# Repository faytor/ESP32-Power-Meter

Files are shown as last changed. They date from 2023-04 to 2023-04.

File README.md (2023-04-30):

# Smart AC Power Meter based on ESP32-C3 module
***

> **⚠ WARNING: Project still in progress.**  
> This project is still under development. However, I have successfully tested the following features: 
***
- Flashing and debugging the ESP32 module via USB-C ✅
- Blink the LED on GPIO pin 0 ✅
- I2C communication with the ACS37800 IC (read and write registers) ✅
- Fixed a schematic/hardware bug in the power switch logic (not shown in the image below) ✅
***
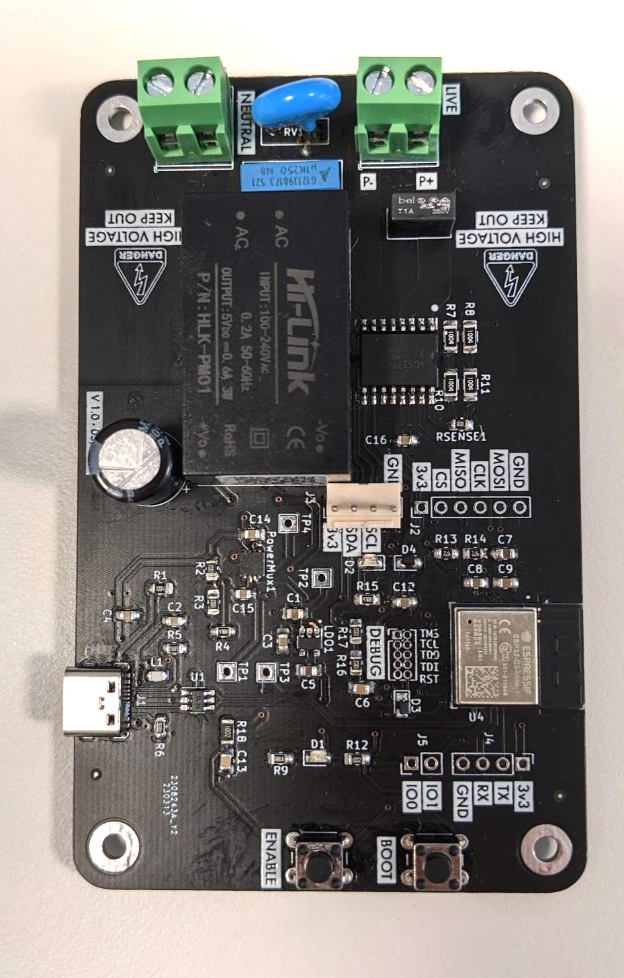
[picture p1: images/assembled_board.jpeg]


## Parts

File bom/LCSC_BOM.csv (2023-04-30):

LCSC Part Number | Manufacture Part Number | Manufacturer | Customer NO. | Package | Description | RoHS | Order Qty. | Min\Mult Order Qty. | Unit Price | Order Price
C165948 | TYPE-C-31-M-12 | Korean Hroparts Elec |  | SMD | 5A 1 16 Female Type-C SMD USB Connectors ROHS | YES | 5 | 5\5 | 0.217400 | 1.09
C209903 | HLK-PM01 | HI-LINK |  | Plugin | 5V 0.6A 90VAC~265VAC 120V~350V 3W AC-DC 73% Plugin Power Modules ROHS | YES | 2 | 1\1 | 2.512.100 | 5.02
C709041 | JL500-50802G01 | JILN |  | P=5.08mm | Copper -40℃~+105℃ 15A 300V Green Tin 14~26 250℃ 5.08mm 0.2~2 1 2 P=5.08mm Screw terminal ROHS | YES | 10 | 5\5 | 0.132500 | 1.33
C363068 | STE10D561K1EQ0FST0R0 | STE(Songtian Elec) |  | Plugin | 925V 460V 350V 504V~616V Plugin Varistors ROHS | YES | 5 | 5\5 | 0.081400 | 0.41
C437645 | 50ZLH220MEFCT810X16 | Rubycon |  | Plugin,D10xL16mm | 220uF 50V 10mm 16mm 5mm ±20% 10000hrs@105℃ Plugin,D10xL16mm Aluminum Electrolytic Capacitors - Leaded ROHS | YES | 5 | 5\5 | 0.178200 | 0.89
C117677 | B32521C3104K189 | TDK |  | Plugin,P=10mm | ±10% 250V 100nF -55℃~+125℃ Metallized Polyester Plugin,P=10mm Film Capacitors ROHS | YES | 5 | 1\1 | 0.271900 | 1.36
C434330 | MEF104K250D02 | Jimson |  | Plugin,P=10mm | ±10% 250V 100nF -40℃~+85℃ PET Plugin,P=10mm Film Capacitors ROHS | YES | 5 | 5\5 | 0.079400 | 0.40
C479110 | PTFR1206B1M00P9 | Resistor.Today |  | 1206 | 250mW Thin Film Resistor 200V ±25ppm/℃ ±0.1% -55℃~+125℃ 1MΩ 1206 Chip Resistor - Surface Mount ROHS | YES | 20 | 5\5 | 0.208900 | 4.18
C2849373 | PTFR0805B8K20P9 | Resistor.Today |  | 805 | 0.13W Thin Film Resistor 150V ±0.1% -55℃~+155℃ 8.2kΩ 0805 Chip Resistor - Surface Mount ROHS | YES | 10 | 5\5 | 0.140300 | 1.40
C140321 | TPS2115ADRBR | Texas Instruments |  | SON-8(3x3) | SON-8(3x3) Battery Management ICs ROHS | YES | 3 | 1\1 | 1.778.700 | 5.34
C9055 | SPX3819M5-L-3-3/TR | MaxLinear |  | SOT-23-5 | 500mA 70dB Fixed 3.3V~3.3V Positive 16V SOT-23-5 Linear Voltage Regulators (LDO) ROHS | YES | 5 | 1\5 | 0.167900 | 0.84
C7519 | USBLC6-2SC6 | STMicroelectronics |  | SOT-23-6 | 6V 17V Unidirectional 5.25V SOT-23-6 ESD Protection Devices ROHS | YES | 5 | 5\5 | 0.120500 | 0.60
C964055 | HBLS2012-2N2S | HYHONGYEX |  | 805 | 600mA 2.2nH 100mΩ 0805 Inductors (SMD) ROHS | YES | 50 | 1\50 | 0.010400 | 0.52
C2895038 | B-2101S10P-B110 | Ckmtw(Shenzhen Cankemeng) |  | Plugin,P=1.27mm | 1A Straight Square Pins 1mm 3mm -40℃~+105℃ 1.8mm 10 1.27mm 双排 Black 1.27mm 2x5P Plugin,P=1.27mm Pin Headers ROHS | YES | 5 | 5\5 | 0.079200 | 0.40
C193404 | 1N4007WS | MDD（Microdiode Electronics） |  | SOD-323 | 1A 1kV 1.1V@1A SOD-323 Diodes - General Purpose ROHS | YES | 20 | 20\20 | 0.031400 | 0.63
C2838502 | ESP32-C3-MINI-1-N4 | Espressif Systems |  | SMD,13.2x16.6mm | SMD,13.2x16.6mm RF Modules ROHS | YES | 2 | 1\1 | 2.545.500 | 5.09
C5355440 | A-SC170Y3C-A01-3T | Amicc |  | 805 | 20mA Colorless transparence 140mcd 588.5nm~594.5nm -40℃~+85℃ 正贴 yellow 140° 60mW 1.7V~2.3V 0805 Light Emitting Diodes (LED) ROHS | YES | 10 | 10\10 | 0.054700 | 0.55
C520082 | CC0805JRX7R7BB104 | YAGEO |  | 805 | 16V 100nF X7R ±5% 0805 Multilayer Ceramic Capacitors MLCC - SMD/SMT ROHS | YES | 50 | 50\50 | 0.012400 | 0.62
C2180714 | CC0805MRX7R8BB103 | YAGEO |  | 805 | 25V 10nF X7R ±20% 0805 Multilayer Ceramic Capacitors MLCC - SMD/SMT ROHS | YES | 50 | 50\50 | 0.006500 | 0.33
C87157 | EMK212BJ106KG-T | Taiyo Yuden |  | 805 | 16V 10uF X5R ±10% 0805 Multilayer Ceramic Capacitors MLCC - SMD/SMT ROHS | YES | 50 | 50\50 | 0.015900 | 0.80
C204548 | CR0805-FX-5101ELF | BOURNS |  | 805 | 125mW ±100ppm/℃ ±1% 5.1kΩ 0805 Chip Resistor - Surface Mount ROHS | YES | 50 | 50\50 | 0.012400 | 0.62
C204522 | CR0805-FX-4700ELF | BOURNS |  | 805 | 125mW Thick Film Resistors ±100ppm/℃ ±1% -55℃~+155℃ 470Ω 0805 Chip Resistor - Surface Mount ROHS | YES | 50 | 50\50 | 0.012800 | 0.64
C237770 | RMCF0805JT4K70 | SEI(Stackpole Elec) |  | 805 | 125mW 150V ±200ppm/℃ ±5% -55℃~+125℃ 4.7kΩ 0805 Chip Resistor - Surface Mount ROHS | YES | 50 | 50\50 | 0.006800 | 0.34

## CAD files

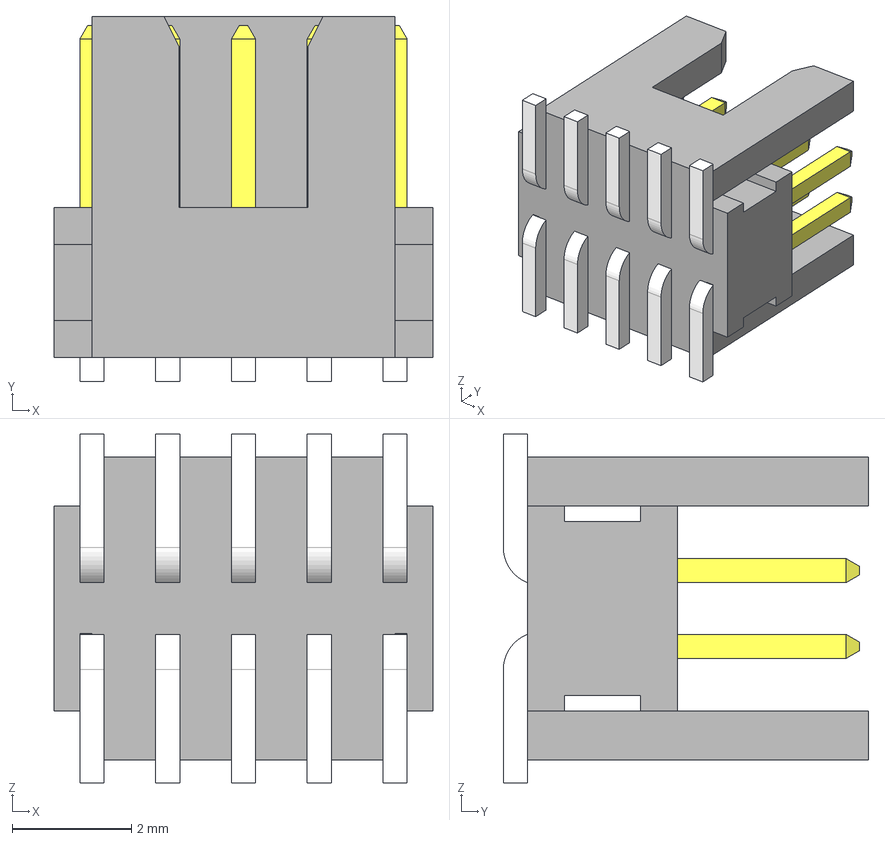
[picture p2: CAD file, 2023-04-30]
KicadLibrary/FTSH-105-01-F-DV-P-TR/FTSH-105-01-F-DV-P-TR.step
6.35 x 6.12 x 5.84 mm
FTSH-105-01-F-DV-K_pins2
FTSH-105-01-F-DV-K_pins1
FTSH-105-01-F-DV-K_body

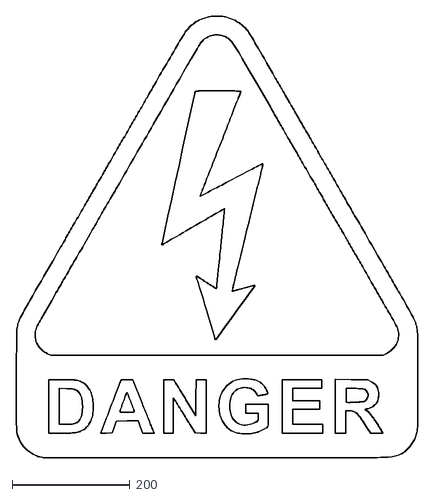
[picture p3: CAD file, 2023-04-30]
KicadLibrary/HighVoltageDanger.dxf
681.1 x 749.9

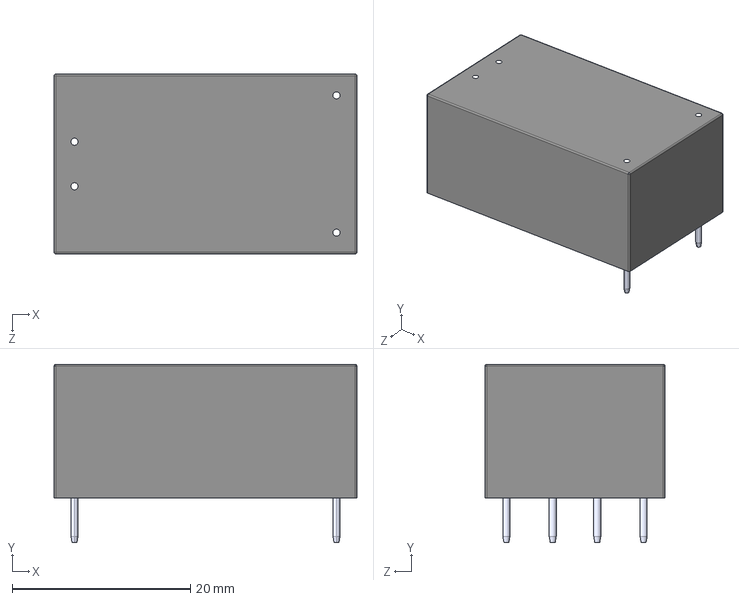
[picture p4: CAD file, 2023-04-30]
KicadLibrary/hlk_pm01/hlk-pm01--3DModel-STEP-56544.STEP
34.0 x 20.0 x 20.2 mm

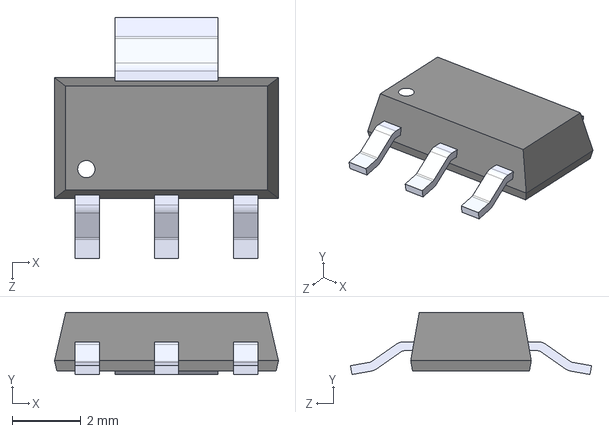
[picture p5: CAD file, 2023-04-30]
KicadLibrary/LD1117S33CTR/LD1117S33CTR.step
6.50 x 1.80 x 7.00 mm

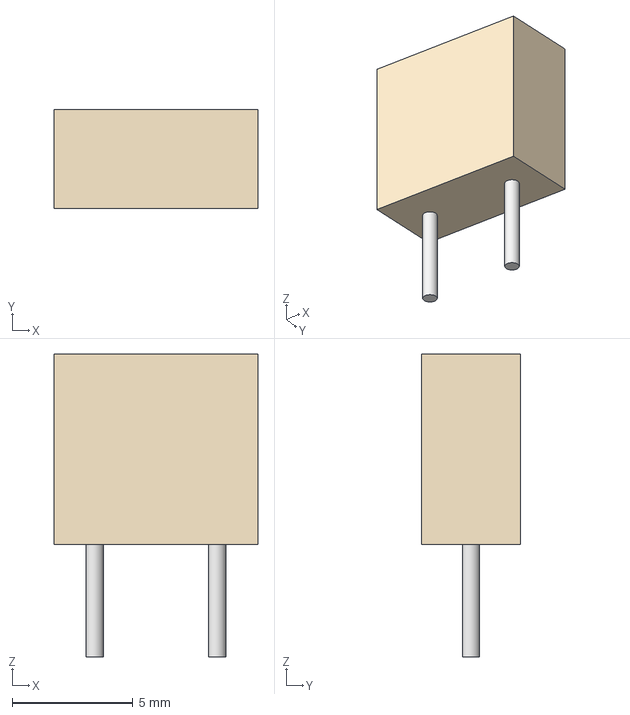
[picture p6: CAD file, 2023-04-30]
KicadLibrary/RST-1-BULK/RST_BEL.step
8.46 x 4.09 x 12.6 mm

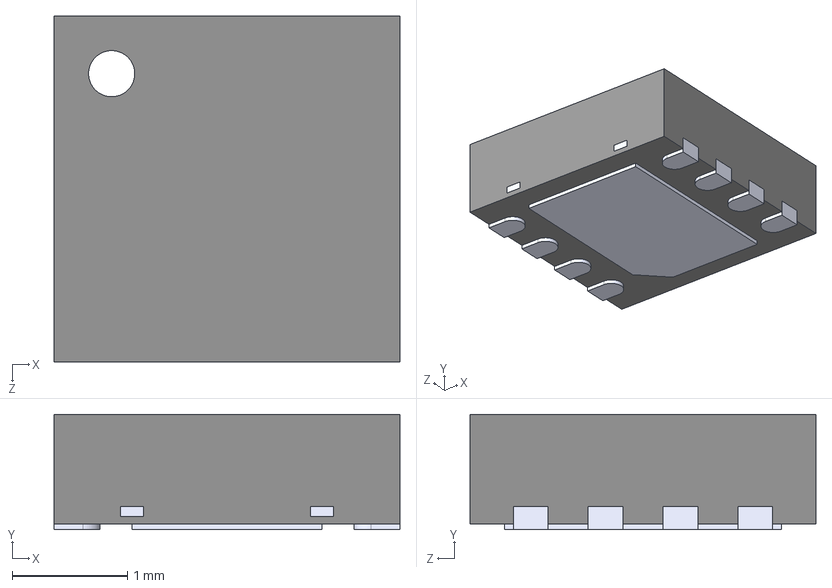
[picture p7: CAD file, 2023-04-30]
KicadLibrary/TPS2115ADRBR/TPS2115ADRBR--3DModel-STEP-56544.STEP
3.00 x 1.00 x 3.00 mm

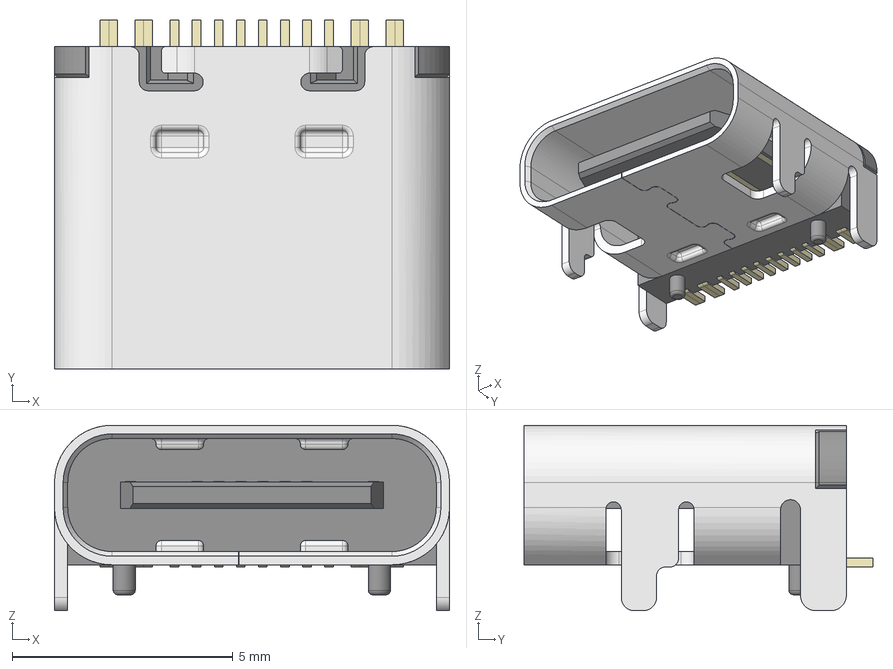
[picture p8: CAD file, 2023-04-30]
KicadLibrary/usb_3d/type-c-31-m-12-1.snapshot.5/HRO_TYPE-C-31-M-12.step
8.95 x 7.90 x 4.20 mm

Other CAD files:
KicadLibrary/ACS37800KMACTR-090B3-I2C/Allegro/soic127p1030x265-16n.psm

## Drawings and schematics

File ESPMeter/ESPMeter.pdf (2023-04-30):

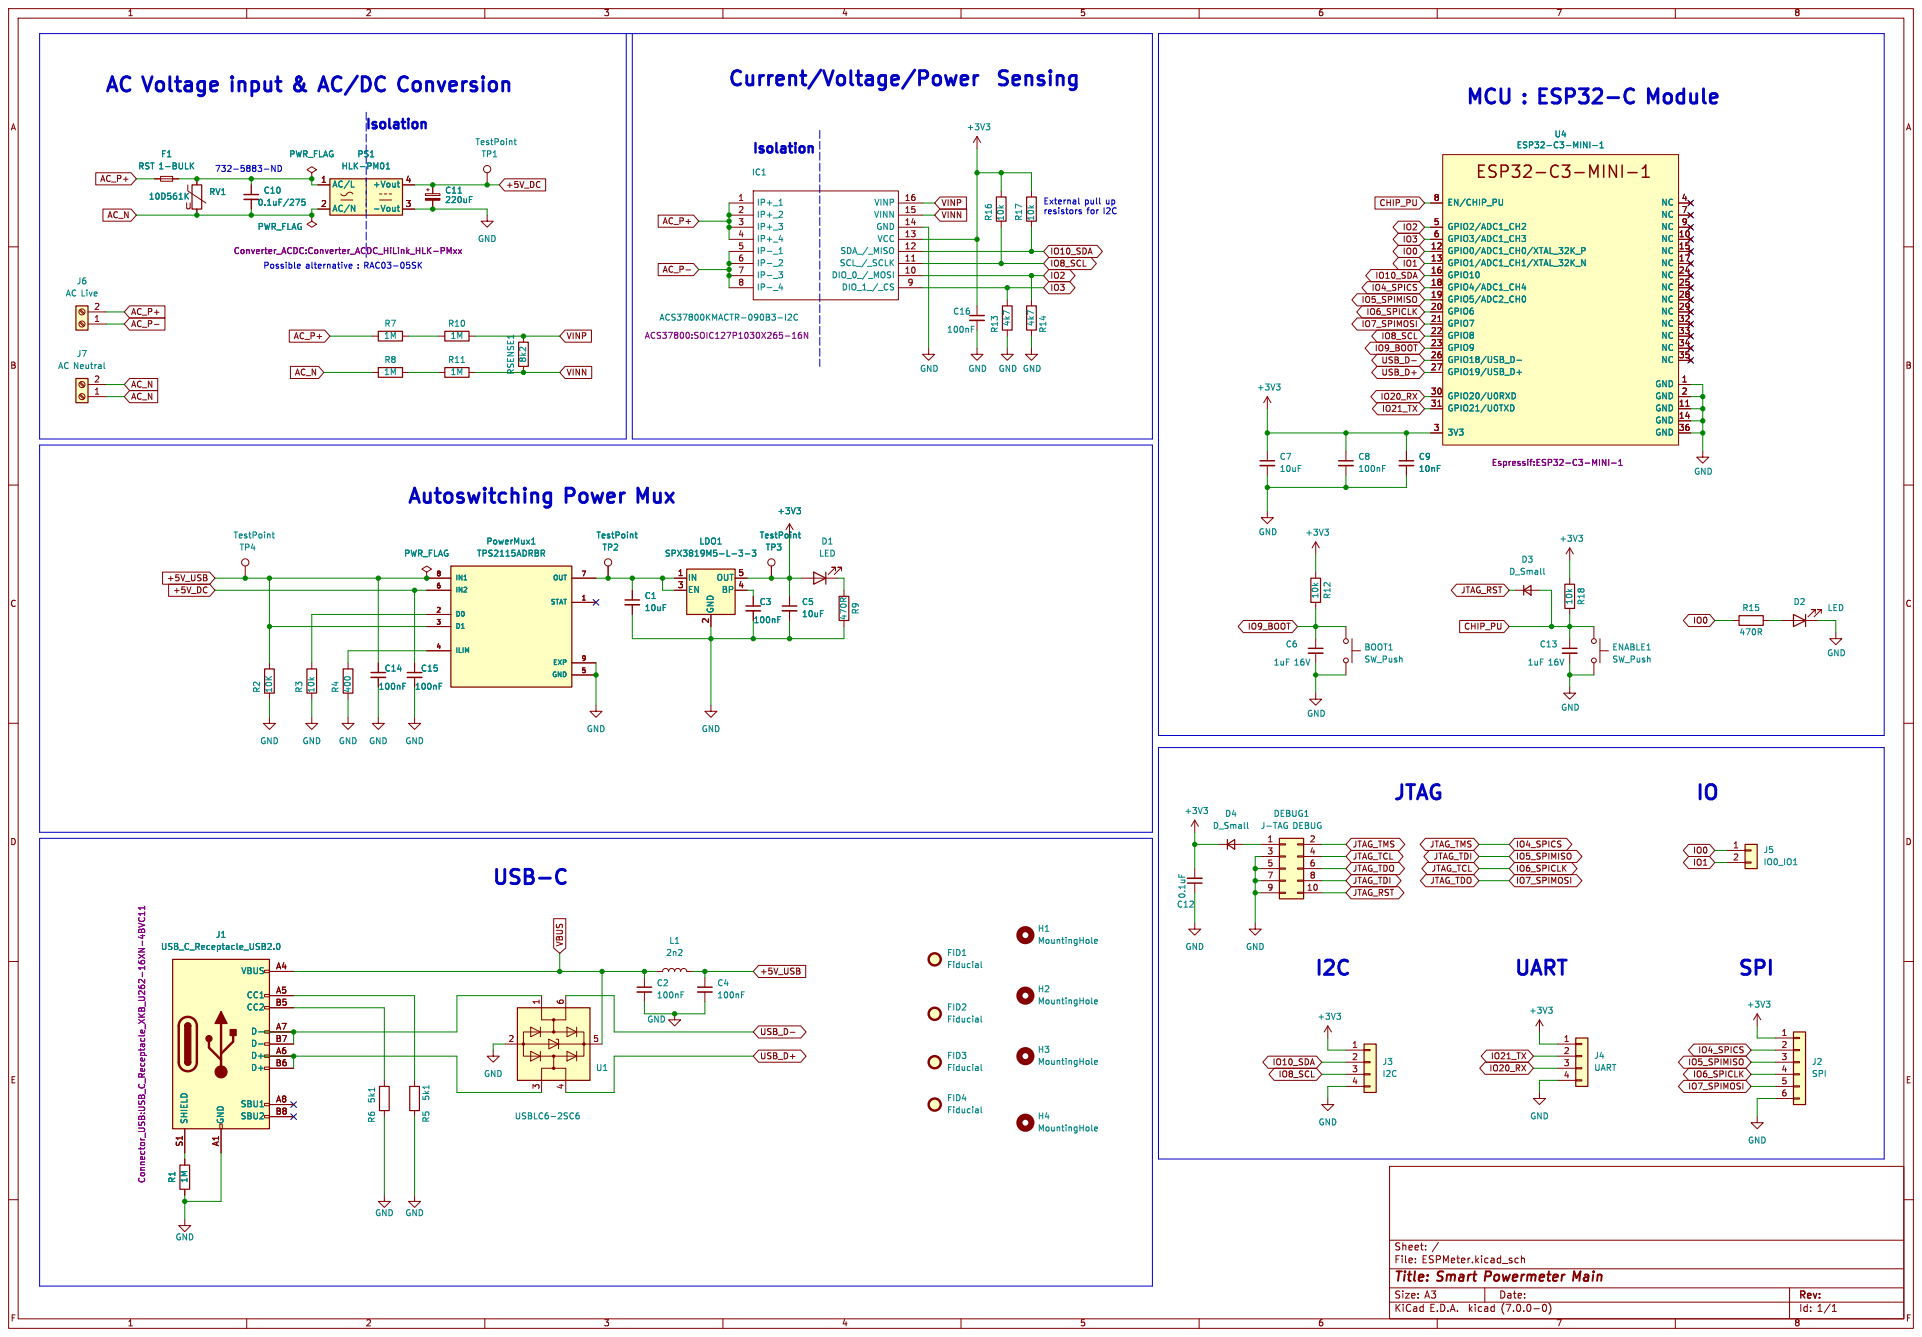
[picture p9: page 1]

resistors for I2C AC Voltage input & AC/DC Conversion

2 EN 3 BP 4 OUT 5 +3V3 TP2 TestPoint C5

Id: 1/1 Title: Smart Powermeter Main

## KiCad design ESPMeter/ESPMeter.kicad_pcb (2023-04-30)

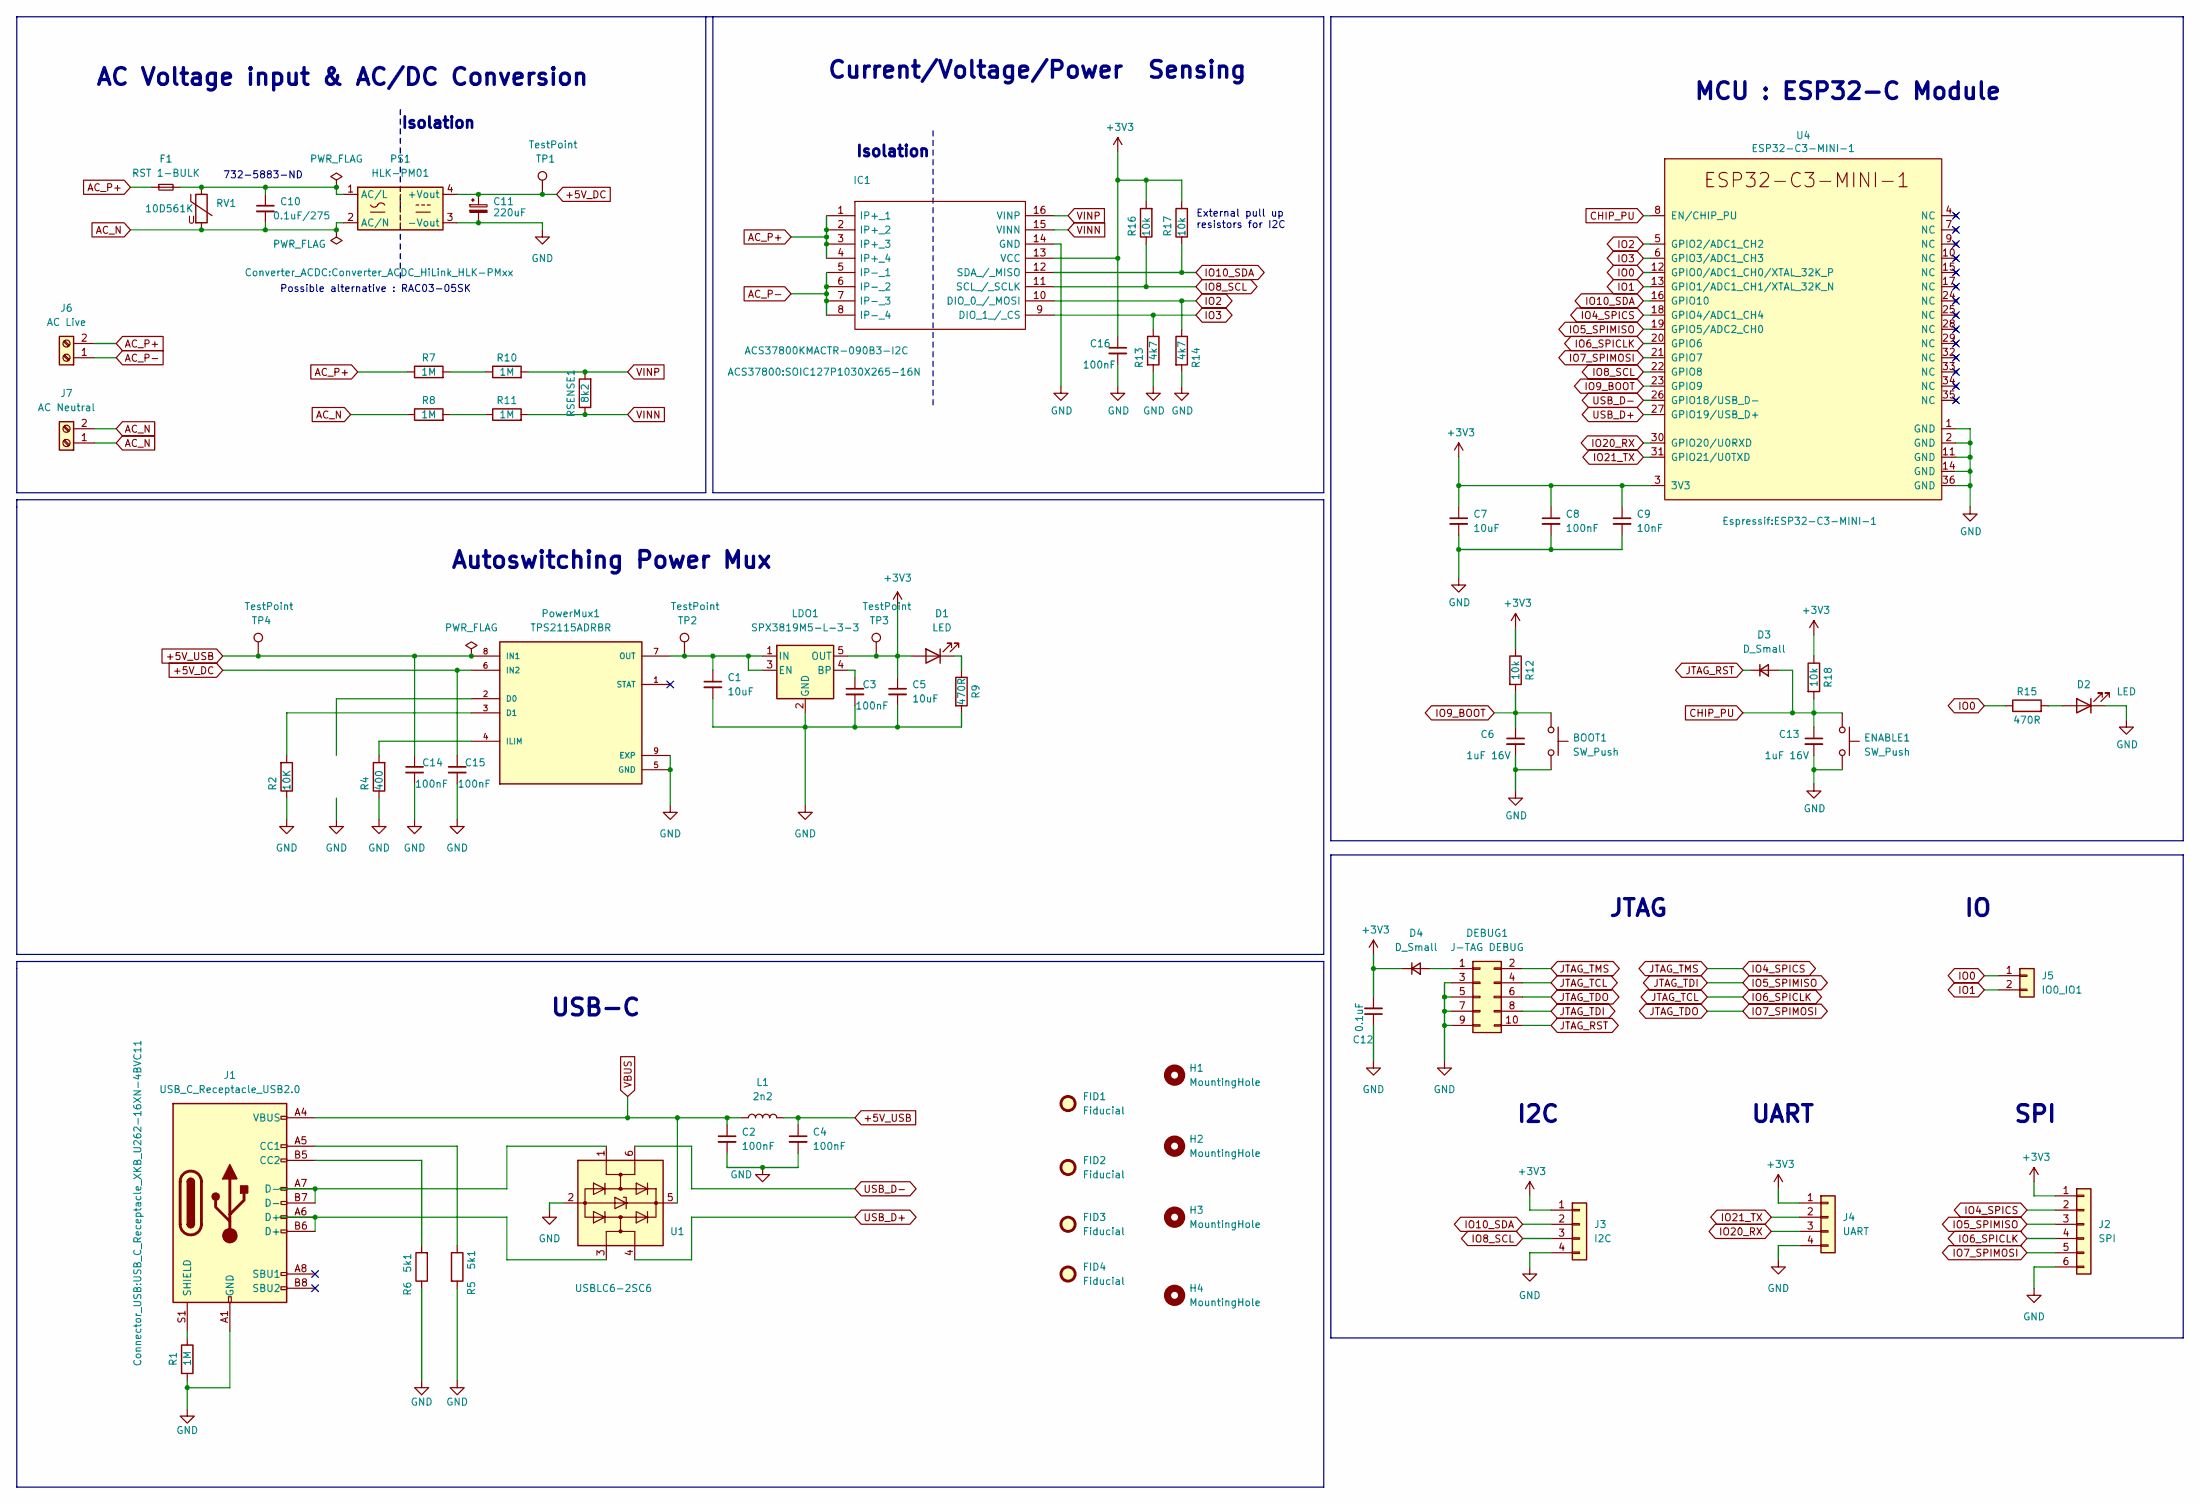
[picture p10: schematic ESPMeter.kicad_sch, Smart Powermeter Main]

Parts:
BOOT1: SW_Push; SW_PUSH_6mm_H4.3mm
C1, C5, C7: 10uF; C_0805_2012Metric_Pad1.18x1.45mm_HandSolder
C2, C3, C4, C8, C14, C15, C16: 100nF; C_0805_2012Metric_Pad1.18x1.45mm_HandSolder
C6, C13: 1uF 16V; C_0805_2012Metric_Pad1.18x1.45mm_HandSolder; LCSC C52923
C9: 10nF; C_0805_2012Metric_Pad1.18x1.45mm_HandSolder
C10: 0.1uF/275; C_Rect_L13.0mm_W8.0mm_P10.00mm_FKS3_FKP3_MKS4
C11: 220uF; CP_Radial_D10.0mm_P5.00mm
C12: 0.1uF; C_0805_2012Metric_Pad1.18x1.45mm_HandSolder
D1: LED; LED_0805_2012Metric_Pad1.15x1.40mm_HandSolder
D2: LED; LED_0805_2012Metric_Pad1.15x1.40mm_HandSolder; LCSC C2286
D3, D4: D_Small; D_0805_2012Metric_Pad1.15x1.40mm_HandSolder
DEBUG1: J-TAG DEBUG; PinHeader_2x05_P1.27mm_Vertical
ENABLE1: SW_Push; SW_PUSH_6mm_H4.3mm
F1: RST 1-BULK; FUSE_RST-1-BULK
FID1, FID2, FID3, FID4: Fiducial; Fiducial_0.5mm_Mask1.5mm
H1, H2, H3, H4: MountingHole; MountingHole_3.2mm_M3_Pad_TopBottom
IC1: ACS37800KMACTR-090B3-I2C; SOIC127P1030X265-16N; Manufacturer_Part_Number ACS37800KMACTR-090B3-I2C
J1: USB_C_Receptacle_USB2.0; USB_C_Receptacle_XKB_U262-16XN-4BVC11
J2: SPI; PinHeader_1x06_P2.54mm_Vertical
J3: I2C; PinHeader_1x04_P2.54mm_Vertical
J4: UART; PinHeader_1x04_P2.54mm_Vertical
J5: IO0_IO1; PinHeader_1x02_P2.54mm_Vertical
J6: AC Live; TerminalBlock_Phoenix_MKDS-3-2-5.08_1x02_P5.08mm_Horizontal
J7: AC Neutral; TerminalBlock_Phoenix_MKDS-3-2-5.08_1x02_P5.08mm_Horizontal
L1: 2n2; L_0805_2012Metric_Pad1.15x1.40mm_HandSolder
LDO1: SPX3819M5-L-3-3; SOT-23-5
PS1: HLK-PM01; Converter_ACDC_HiLink_HLK-PMxx
PowerMux1: TPS2115ADRBR; SON65P300X300X100-9N
R1: 1M; R_0805_2012Metric_Pad1.20x1.40mm_HandSolder
R2: 10K; R_0805_2012Metric_Pad1.20x1.40mm_HandSolder
R4: 400; R_0805_2012Metric_Pad1.20x1.40mm_HandSolder
R5, R6: 5k1; R_0805_2012Metric_Pad1.20x1.40mm_HandSolder
R7, R8, R10, R11: 1M; R_1206_3216Metric_Pad1.30x1.75mm_HandSolder
R9, R15: 470R; R_0805_2012Metric_Pad1.20x1.40mm_HandSolder
R12, R16, R17, R18: 10k; R_0805_2012Metric_Pad1.20x1.40mm_HandSolder
R13, R14: 4k7; R_0805_2012Metric_Pad1.20x1.40mm_HandSolder
RSENSE1: 8k2; R_0805_2012Metric_Pad1.20x1.40mm_HandSolder
RV1: 10D561K; RV_Disc_D9mm_W3.5mm_P5mm
TP1, TP2, TP3, TP4: TestPoint; TestPoint_THTPad_2.0x2.0mm_Drill1.0mm
U1: USBLC6-2SC6; SOT-23-6_Handsoldering
U4: ESP32-C3-MINI-1; LCSC C2838502

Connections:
+3V3: C5.1, C7.1, C8.1, C9.1, C12.2, C16.1, D1.2 (A), D4.1 (K), IC1.13 (VCC), J2.1, J3.1, J4.1, LDO1.5 (OUT), R12.1, R16.2, R17.2, R18.1, TP3.1, U4.3 (3V3)
+5V_DC: C11.1, C15.1, PS1.4 (+Vout), PowerMux1.6 (IN2), TP1.1
AC_N: C10.2, J7.1, J7.2, PS1.2 (AC/N), R8.1, RV1.2
AC_P+: F1.1, IC1.1 (IP+_1), IC1.2 (IP+_2), IC1.3 (IP+_3), IC1.4 (IP+_4), J6.2, R7.1
AC_P-: IC1.5 (IP-_1), IC1.6 (IP-_2), IC1.7 (IP-_3), IC1.8 (IP-_4), J6.1
CHIP_PU: C13.1, D3.2 (A), ENABLE1.1, R18.2, U4.8 (EN/CHIP_PU)
GND: BOOT1.2, C1.2, C2.2, C3.2, C4.2, C5.2, C6.2, C7.2, C8.2, C9.2, C11.2, C12.1, C13.2, C14.2, C15.2, C16.2, D2.1 (K), DEBUG1.3, DEBUG1.5, DEBUG1.7, DEBUG1.9, ENABLE1.2, IC1.14 (GND), J1.A1 (GND), J1.A12 (GND), J1.B1 (GND), J1.B12 (GND), J2.6, J3.4, J4.4, LDO1.2 (GND), PS1.3 (-Vout), PowerMux1.5 (GND), PowerMux1.9 (EXP), R1.2, R2.1, R4.1, R5.2, R6.1, R9.2, R13.2, R14.2, U1.2 (GND), U4.1 (GND), U4.2 (GND), U4.11 (GND), U4.14 (GND), U4.36 (GND); also elsewhere on the board
IO0: J5.1, R15.1, U4.12 (GPIO0/ADC1_CH0/XTAL_32K_P)
IO1: J5.2, U4.13 (GPIO1/ADC1_CH1/XTAL_32K_N)
IO2: IC1.10 (DIO_0_/_MOSI), R14.1, U4.5 (GPIO2/ADC1_CH2)
IO3: IC1.9 (DIO_1_/_CS), R13.1, U4.6 (GPIO3/ADC1_CH3)
IO4_SPICS: DEBUG1.2, J2.2, U4.18 (GPIO4/ADC1_CH4)
IO5_SPIMISO: DEBUG1.8, J2.3, U4.19 (GPIO5/ADC2_CH0)
IO6_SPICLK: DEBUG1.4, J2.4, U4.20 (GPIO6)
IO7_SPIMOSI: DEBUG1.6, J2.5, U4.21 (GPIO7)
IO8_SCL: IC1.11 (SCL_/_SCLK), J3.3, R16.1, U4.22 (GPIO8)
IO9_BOOT: BOOT1.1, C6.1, R12.2, U4.23 (GPIO9)
IO10_SDA: IC1.12 (SDA_/_MISO), J3.2, R17.1, U4.16 (GPIO10)
IO20_RX: J4.3, U4.30 (GPIO20/U0RXD)
IO21_TX: J4.2, U4.31 (GPIO21/U0TXD)
JTAG_RST: D3.1 (K), DEBUG1.10
unnamed: C10.1, F1.2, PS1.1 (AC/L), RV1.1
unnamed: D1.1 (K), R9.1
unnamed: D2.2 (A), R15.2
unnamed: D4.2 (A), DEBUG1.1
unnamed: J1.A5 (CC1), R5.1
unnamed: J1.B5 (CC2), R6.2
unnamed: J1.A6 (D+), J1.B6 (D+), U1.3 (I/O2)
unnamed: J1.A7 (D-), J1.B7 (D-), U1.1 (I/O1)
unnamed: J1.S1 (SHIELD), R1.1
unnamed: C3.1, LDO1.4 (BP)
unnamed: C1.1, LDO1.1 (IN), LDO1.3 (EN), PowerMux1.7 (OUT), TP2.1
unnamed 32: PowerMux1.2 (D0); also elsewhere on the board
unnamed: PowerMux1.4 (ILIM), R4.2
unnamed: R7.2, R10.1
unnamed: R8.2, R11.1
USB_D+: U1.4 (I/O2), U4.27 (GPIO19/USB_D+)
USB_D-: U1.6 (I/O1), U4.26 (GPIO18/USB_D-)
VBUS: C2.1, J1.A4 (VBUS), J1.A9 (VBUS), J1.B4 (VBUS), J1.B9 (VBUS), L1.1, U1.5 (VBUS)
VINN: IC1.15 (VINN), R11.2, RSENSE1.1
VINP: IC1.16 (VINP), R10.2, RSENSE1.2

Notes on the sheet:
UART
External pull up resistors for I2C
SPI
AC Voltage input & AC/DC Conversion
JTAG
Current/Voltage/Power Sensing
I2C
Autoswitching Power Mux
Isolation
Possible alternative : RAC03-05SK
USB-C
MCU : ESP32-C Module
732-5883-ND

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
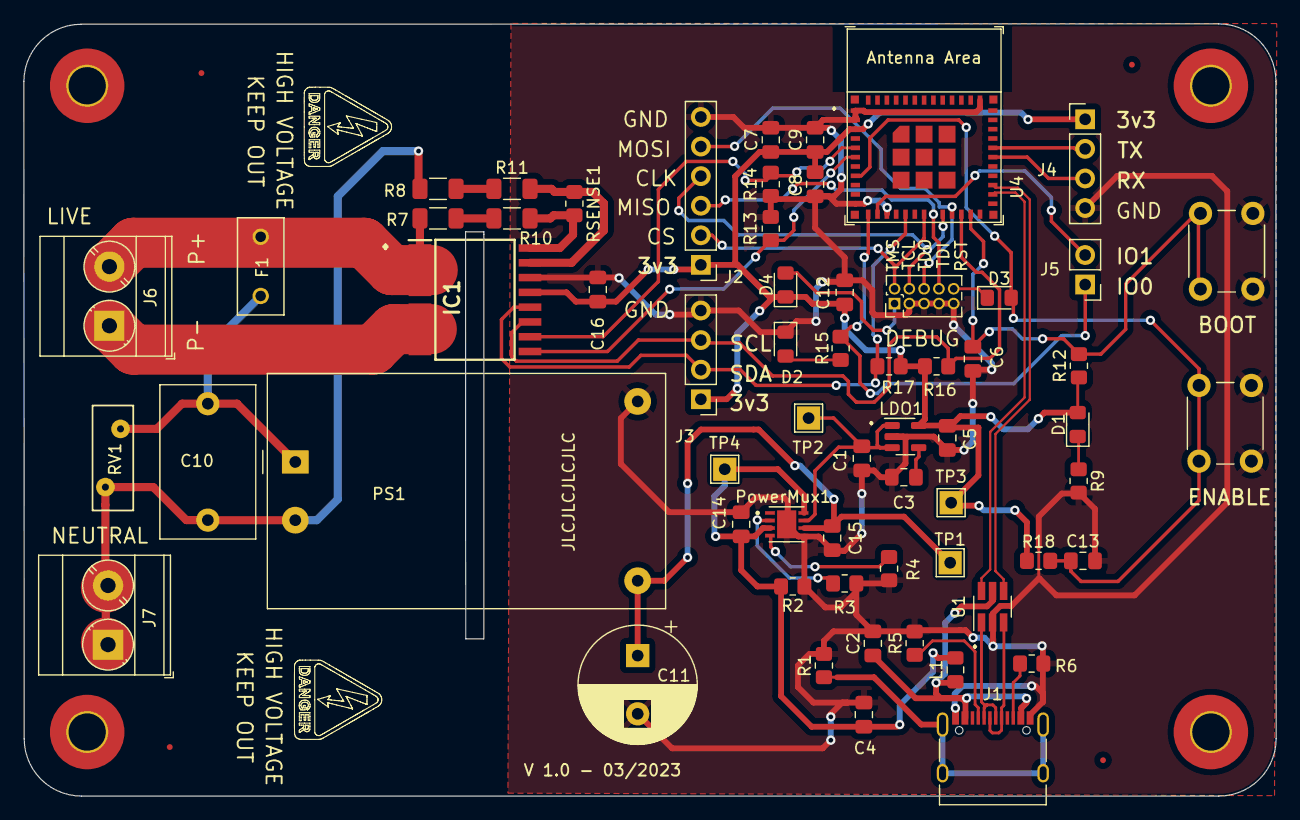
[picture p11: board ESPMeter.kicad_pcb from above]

Board: 2 copper layers, 107.5 x 66.3 mm, 70 parts (0 on the bottom side), 42 nets.

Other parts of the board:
R3: 10k; R_0805_2012Metric_Pad1.20x1.40mm_HandSolder

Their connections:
GND: R3.1; also elsewhere on the board
unnamed 32: R3.2; also elsewhere on the board

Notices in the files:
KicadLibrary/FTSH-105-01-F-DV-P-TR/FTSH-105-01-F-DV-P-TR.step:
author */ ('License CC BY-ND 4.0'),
